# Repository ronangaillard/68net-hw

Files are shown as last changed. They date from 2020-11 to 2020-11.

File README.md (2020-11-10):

# 68net



A SCSI to ethernet board

[My blog post](https://ronangaillard.github.io/posts/68net-a-modern-scsi2ethernet-board-part1/) for more background info 

## Contributing

To make sure Kicad and git work fluently run the following before commiting :

```bash
git config --global filter.kicad_project.clean "sed -E 's/^update=.*$/update=Date/'"
git config --global filter.kicad_project.smudge cat
git config --global filter.kicad_sch.clean "sed -E 's/#(PWR|FLG)[0-9]+/#\1?/'"
git config --global filter.kicad_sch.smudge cat
```

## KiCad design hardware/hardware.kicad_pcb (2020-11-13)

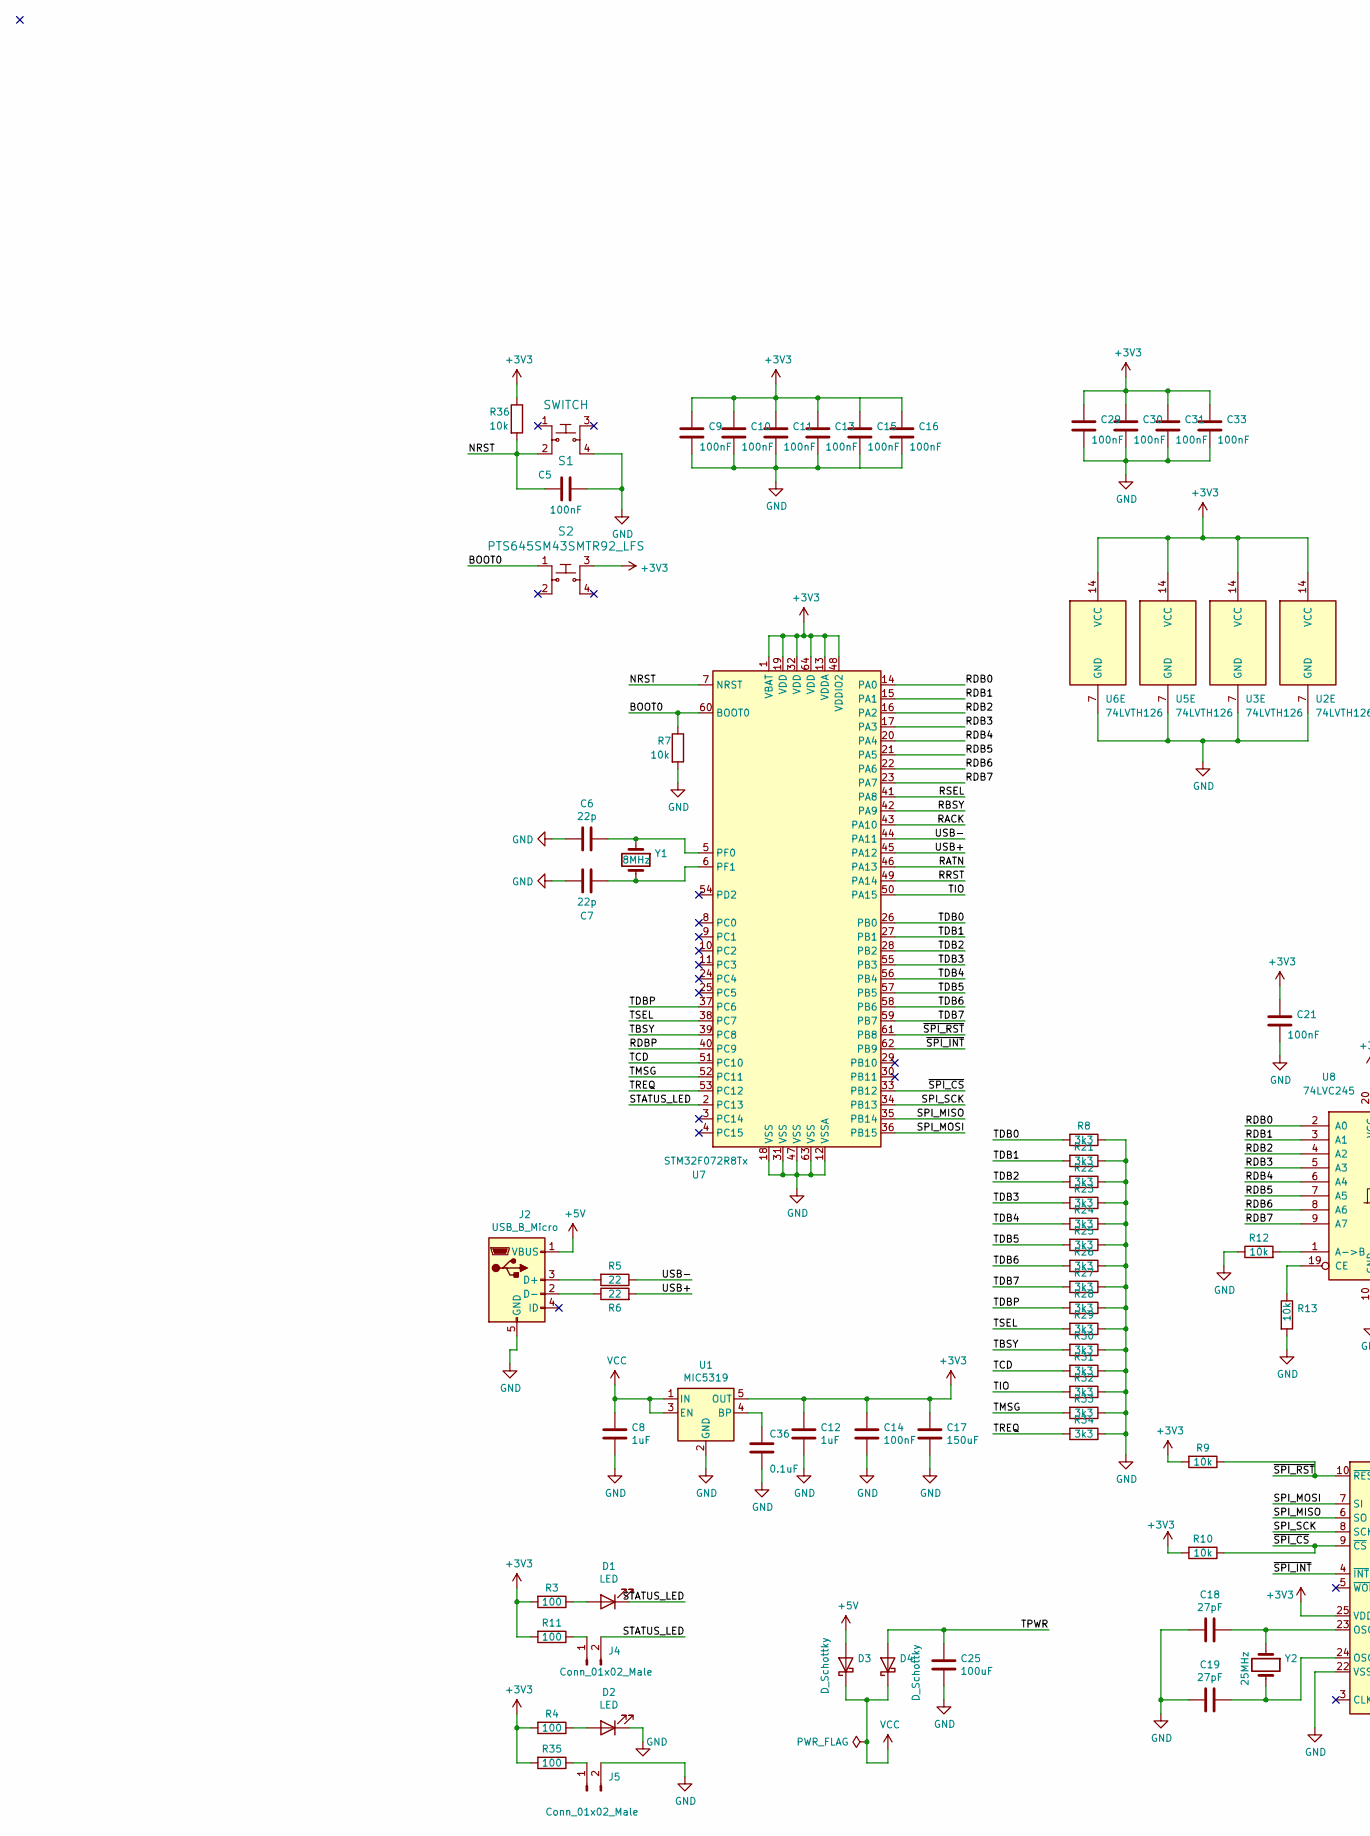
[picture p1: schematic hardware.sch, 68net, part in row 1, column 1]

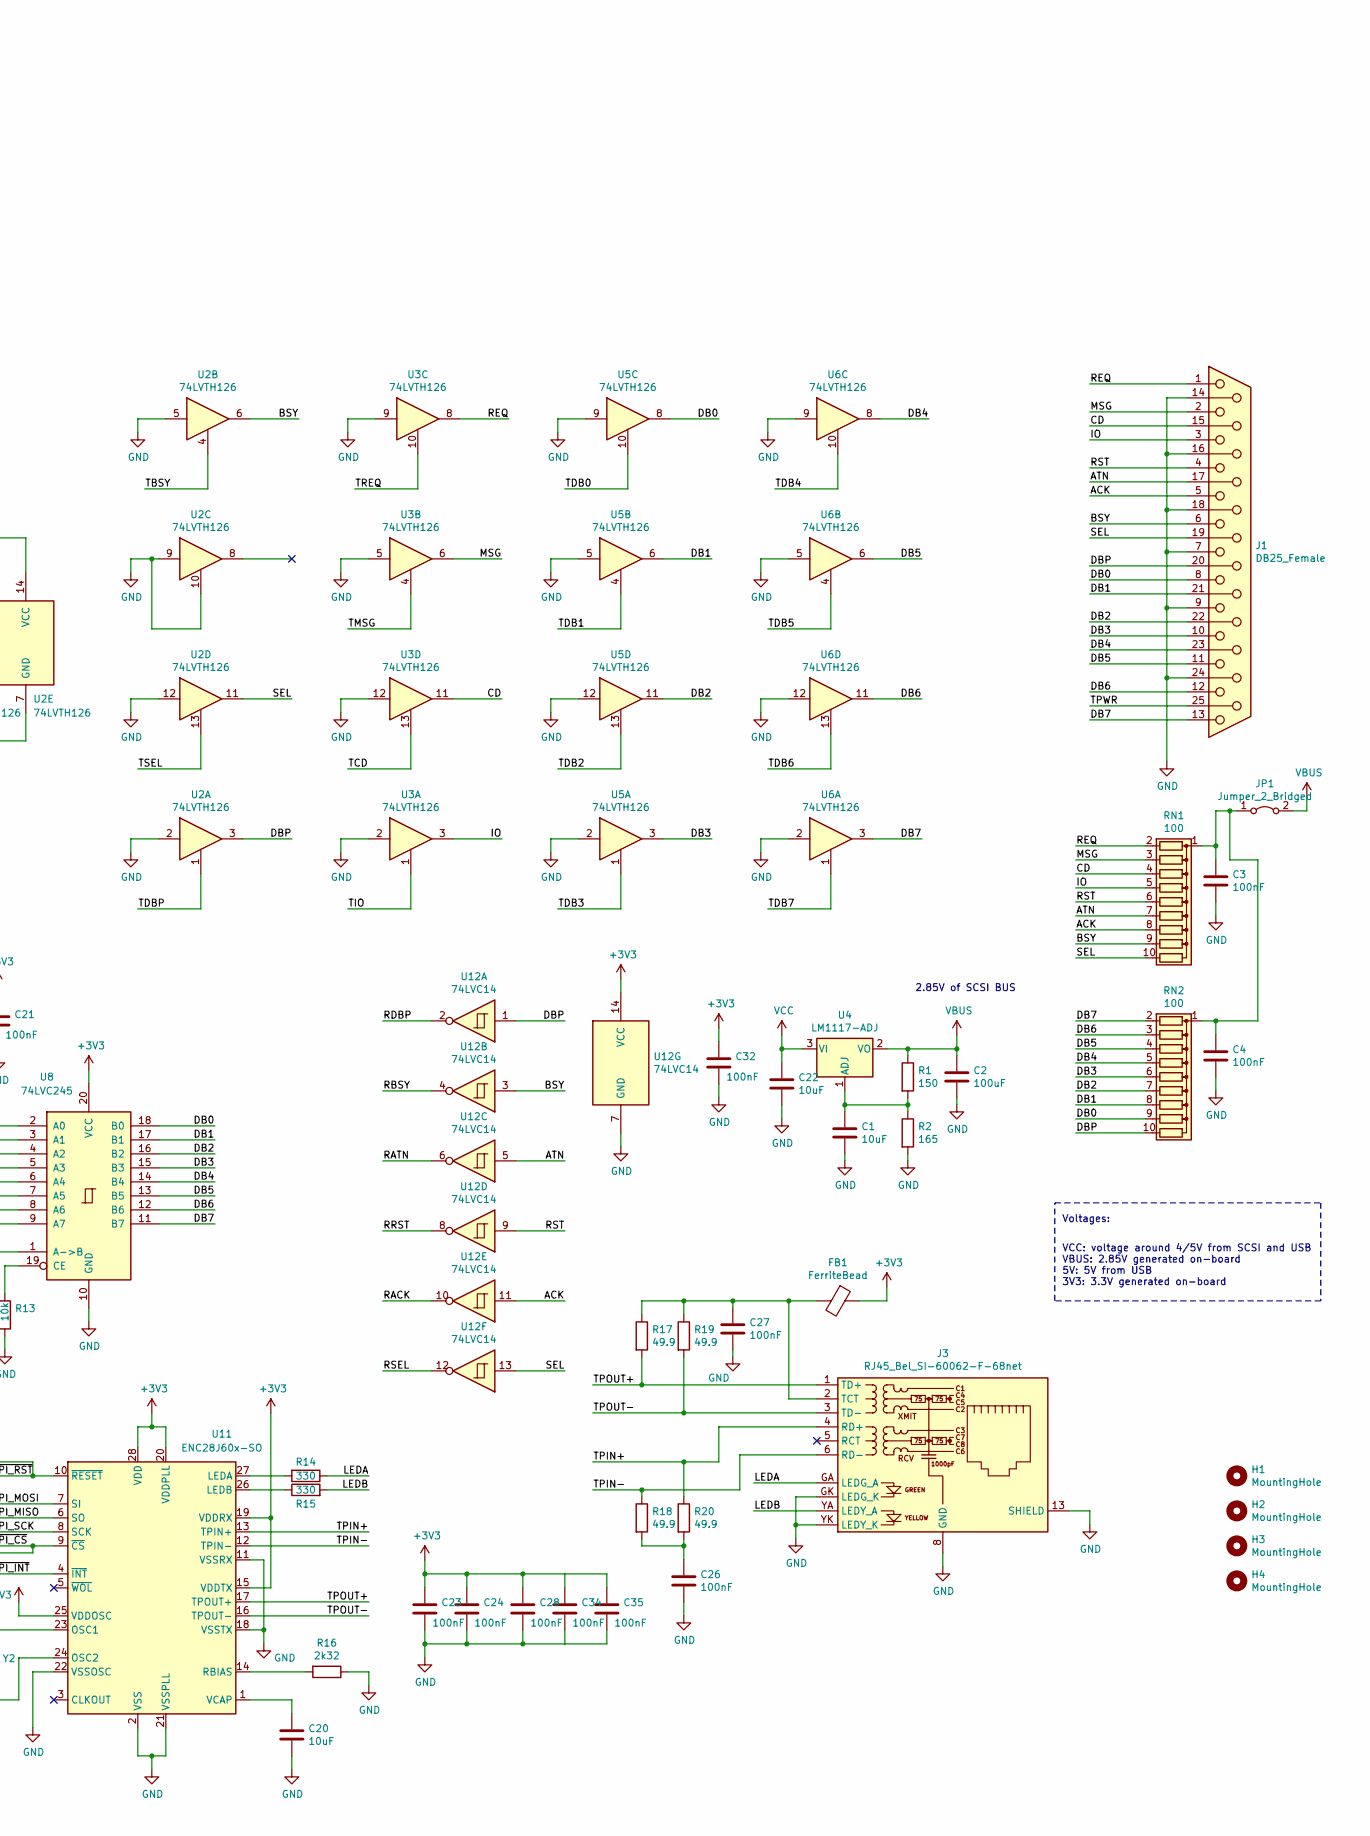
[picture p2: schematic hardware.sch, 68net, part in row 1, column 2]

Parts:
C1, C20, C22: 10uF; C_1206_3216Metric_Pad1.42x1.75mm_HandSolder; Digi-Key_PN 1276-1079-1-ND
C2: 100uF; C_1206_3216Metric_Pad1.42x1.75mm_HandSolder; Digi-Key_PN 1276-1782-1-ND
C3, C4, C5, C9, C10, C11, C13, C14, C15, C16, C21, C23, C24, C26, C27, C28, C29, C30, C31, C32, C33, C34, C35: 100nF; C_1206_3216Metric_Pad1.42x1.75mm_HandSolder; Digi-Key_PN 1276-1017-1-ND
C6, C7: 22p; C_1206_3216Metric_Pad1.42x1.75mm_HandSolder; Digi-Key_PN 1276-1203-1-ND
C8, C12: 1uF; C_1206_3216Metric_Pad1.42x1.75mm_HandSolder; Digi-Key_PN 1276-3091-1-ND
C17: 150uF; C_1206_3216Metric_Pad1.42x1.75mm_HandSolder; Digi-Key_PN 490-13964-1-ND
C18, C19: 27pF; C_1206_3216Metric_Pad1.42x1.75mm_HandSolder; Digi-Key_PN 1276-2827-1-ND
C25: 100uF; CP_Elec_6.3x5.4; Digi-Key_PN 493-2105-1-ND
C36: 0.1uF; C_1206_3216Metric_Pad1.42x1.75mm_HandSolder; Digi-Key_PN CL31B104KBCNNNC
D1, D2: LED; LED_1206_3216Metric_Pad1.42x1.75mm_HandSolder; Digi-Key_PN 60-1456-1-ND
D3, D4: D_Schottky; D_SOD-523; Digi-Key_PN RB521S30T1GOSCT-ND
FB1: FerriteBead; L_0603_1608Metric_Pad1.05x0.95mm_HandSolder; Digi-Key_PN 445-8694-1-ND
H1, H2, H3, H4: MountingHole; MountingHole_3.2mm_M3_Pad
J1: DB25_Female; DSUB-25_Female_Horizontal_Double; Digi-Key_PN 609-1507-ND
J2: USB_B_Micro; TE_2172034-1; Digi-Key_PN 135698-ND
J3: RJ45_Bel_SI-60062-F-68net; SI-60062-F; Digi-Key_PN 380-1106-ND
J4, J5: Conn_01x02_Male; PinHeader_1x02_P2.54mm_Vertical
JP1: Jumper_2_Bridged; PinHeader_1x02_P2.54mm_Vertical
R1: 150; R_0805_2012Metric_Pad1.15x1.40mm_HandSolder; Digi-Key_PN RMCF0805FT150RCT-ND
R2: 165; R_0805_2012Metric_Pad1.15x1.40mm_HandSolder; Digi-Key_PN RMCF0805FT165RCT-ND
R3, R4, R11, R35: 100; R_0805_2012Metric_Pad1.15x1.40mm_HandSolder; Digi-Key_PN RMCF0805FT165RCT-ND
R5, R6: 22; R_0805_2012Metric_Pad1.15x1.40mm_HandSolder; Digi-Key_PN RMCF0603FT22R0CT-ND
R7, R9, R10, R36: 10k; R_0805_2012Metric_Pad1.15x1.40mm_HandSolder; Digi-Key_PN RMCF0603JT10K0CT-ND
R8, R21, R22, R23, R24, R25, R26, R27, R28, R29, R30, R31, R32, R33, R34: 3k3; R_0805_2012Metric_Pad1.15x1.40mm_HandSolder
R12, R13: 10k; R_0805_2012Metric_Pad1.15x1.40mm_HandSolder
R14, R15: 330; R_0805_2012Metric_Pad1.15x1.40mm_HandSolder; Digi-Key_PN RMCF0805JT330RCT-ND
R16: 2k32; R_0805_2012Metric_Pad1.15x1.40mm_HandSolder; Digi-Key_PN RNCF0603DTE2K32CT-ND
R17, R18, R19, R20: 49.9; R_0805_2012Metric_Pad1.15x1.40mm_HandSolder; Digi-Key_PN RNCP0603FTD49R9CT
RN1, RN2: 100; R_Array_SIP10; Digi-Key_PN 4610X-1-101LF-ND
S1: SWITCH; Switch_Tactile_SMD_6x6mm; Digi-Key_PN TL3301AF160QG
S2: PTS645SM43SMTR92_LFS; Switch_Tactile_SMD_6x6mm; Digi-Key_PN TL3301AF160QG
U1: MIC5319; SOT-23-5_HandSoldering; Digi-Key_PN MIC5319-3.3YD5-TR
U2, U3, U5, U6: 74LVTH126; SOIC-14_3.9x8.7mm_P1.27mm; Digi-Key_PN 296-8663-1-ND
U4: LM1117-ADJ; SOT-223; Digi-Key_PN LM1117MPX-ADJ/NOPBCT-ND
U7: STM32F072R8Tx; LQFP-64_10x10mm_P0.5mm; Digi-Key_PN 497-17362-1-ND
U8: 74LVC245; SOIC-20W_7.5x12.8mm_P1.27mm; Digi-Key_PN 296-1232-1-ND
U11: ENC28J60x-SO; SOIC-28W_7.5x17.9mm_P1.27mm; Digi-Key_PN ENC28J60-I/SO-ND
U12: 74LVC14; SOIC-14_3.9x8.7mm_P1.27mm; Digi-Key_PN 296-1699-1-ND
Y1: 8MHz; Crystal_HC49-4H_Vertical; Digi-Key_PN 887-1253-ND
Y2: 25MHz; Crystal_HC49-4H_Vertical; Digi-Key_PN 887-1233-ND

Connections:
+3V3: C9.1, C10.1, C11.1, C12.1, C13.1, C14.1, C15.1, C16.1, C17.1, C21.1, C23.1, C24.1, C28.1, C29.1, C30.1, C31.1, C32.1, C33.1, C34.1, C35.1, FB1.1, R3.2, R4.2, R9.2, R10.2, R11.2, R35.2, R36.1, S2.3, U1.5 (OUT), U2.14 (VCC), U3.14 (VCC), U5.14 (VCC), U6.14 (VCC), U7.1 (VBAT), U7.13 (VDDA), U7.19 (VDD), U7.32 (VDD), U7.48 (VDDIO2), U7.64 (VDD), U8.20 (VCC), U11.15 (VDDTX), U11.19 (VDDRX), U11.20 (VDDPLL), U11.25 (VDDOSC), U11.28 (VDD), U12.14 (VCC)
+5V: D3.2 (A), J2.1 (VBUS)
/ACK: J1.5, RN1.8 (R7), U12.11
/ATN: J1.17, RN1.7 (R6), U12.5
/BOOT0: R7.1, S2.1, U7.60 (BOOT0)
/BSY: J1.6, RN1.9 (R8), U2.6, U12.3
/CD: J1.15, RN1.4 (R3), U3.11
/DB0: J1.8, RN2.9 (R8), U5.8, U8.18 (B0)
/DB1: J1.21, RN2.8 (R7), U5.6, U8.17 (B1)
/DB2: J1.22, RN2.7 (R6), U5.11, U8.16 (B2)
/DB3: J1.10, RN2.6 (R5), U5.3, U8.15 (B3)
/DB4: J1.23, RN2.5 (R4), U6.8, U8.14 (B4)
/DB5: J1.11, RN2.4 (R3), U6.6, U8.13 (B5)
/DB6: J1.12, RN2.3 (R2), U6.11, U8.12 (B6)
/DB7: J1.13, RN2.2 (R1), U6.3, U8.11 (B7)
/DBP: J1.20, RN2.10 (R9), U2.3, U12.1
/IO: J1.3, RN1.5 (R4), U3.3
/LEDA: J3.GA (LEDG_A), R14.1
/LEDB: J3.YA (LEDY_A), R15.2
/MSG: J1.2, RN1.3 (R2), U3.6
/NRST: C5.2, R36.2, S1.2, U7.7 (NRST)
/RACK: U7.43 (PA10), U12.10
/RATN: U7.46 (PA13), U12.6
/RBSY: U7.42 (PA9), U12.4
/RDB0: U7.14 (PA0), U8.2 (A0)
/RDB1: U7.15 (PA1), U8.3 (A1)
/RDB2: U7.16 (PA2), U8.4 (A2)
/RDB3: U7.17 (PA3), U8.5 (A3)
/RDB4: U7.20 (PA4), U8.6 (A4)
/RDB5: U7.21 (PA5), U8.7 (A5)
/RDB6: U7.22 (PA6), U8.8 (A6)
/RDB7: U7.23 (PA7), U8.9 (A7)
/RDBP: U7.40 (PC9), U12.2
/REQ: J1.1, RN1.2 (R1), U3.8
/RRST: U7.49 (PA14), U12.8
/RSEL: U7.41 (PA8), U12.12
/RST: J1.4, RN1.6 (R5), U12.9
/SEL: J1.19, RN1.10 (R9), U2.11, U12.13
/SPI_MISO: U7.35 (PB14), U11.6 (SO)
/SPI_MOSI: U7.36 (PB15), U11.7 (SI)
/SPI_SCK: U7.34 (PB13), U11.8 (SCK)
/STATUS_LED: D1.1 (K), J4.2, U7.2 (PC13)
/TBSY: R30.2, U2.4, U7.39 (PC8)
/TCD: R31.2, U3.13, U7.51 (PC10)
/TDB0: R8.2, U5.10, U7.26 (PB0)
/TDB1: R21.2, U5.4, U7.27 (PB1)
/TDB2: R22.2, U5.13, U7.28 (PB2)
/TDB3: R23.2, U5.1, U7.55 (PB3)
/TDB4: R24.2, U6.10, U7.56 (PB4)
/TDB5: R25.2, U6.4, U7.57 (PB5)
/TDB6: R26.2, U6.13, U7.58 (PB6)
/TDB7: R27.2, U6.1, U7.59 (PB7)
/TDBP: R28.2, U2.1, U7.37 (PC6)
/TIO: R32.2, U3.1, U7.50 (PA15)
/TMSG: R33.2, U3.4, U7.52 (PC11)
/TPIN+: J3.4 (RD+), R20.1, U11.13 (TPIN+)
/TPIN-: J3.6 (RD-), R18.1, U11.12 (TPIN-)
/TPOUT+: J3.1 (TD+), R17.2, U11.17 (TPOUT+)
/TPOUT-: J3.3 (TD-), R19.2, U11.16 (TPOUT-)
/TPWR: C25.1, D4.2 (A), J1.25
/TREQ: R34.2, U3.10, U7.53 (PC12)
/TSEL: R29.2, U2.13, U7.38 (PC7)
/USB+: R6.2, U7.45 (PA12)
/USB-: R5.1, U7.44 (PA11)
/~SPI_CS~: R10.1, U7.33 (PB12), U11.9 (~CS)
/~SPI_INT~: U7.62 (PB9), U11.4 (~INT)
/~SPI_RST~: R9.1, U7.61 (PB8), U11.10 (~RESET)
GND: C1.2, C2.2, C3.2, C4.2, C5.1, C6.2, C7.2, C8.2, C9.2, C10.2, C11.2, C12.2, C13.2, C14.2, C15.2, C16.2, C17.2, C18.2, C19.2, C20.2, C21.2, C22.2, C23.2, C24.2, C25.2, C26.2, C27.2, C28.2, C29.2, C30.2, C31.2, C32.2, C33.2, C34.2, C35.2, C36.2, D2.1 (K), J1.7, J1.9, J1.14, J1.16, J1.18, J1.24, J2.5 (GND), J3.8 (GND), J3.13 (SHIELD), J3.GK (LEDG_K), J3.YK (LEDY_K), J5.2, R2.2, R7.2, R8.1, R12.1, R13.2, R16.1, R21.1, R22.1, R23.1, R24.1, R25.1, R26.1, R27.1, R28.1, R29.1, R30.1, R31.1, R32.1, R33.1, R34.1, S1.4, U1.2 (GND), U2.2, U2.5, U2.7 (GND), U2.9, U2.10, U2.12, U3.2, U3.5, U3.7 (GND), U3.9, U3.12, U5.2, U5.5, U5.7 (GND), U5.9, U5.12, U6.2, U6.5, U6.7 (GND), U6.9, U6.12, U7.12 (VSSA), U7.18 (VSS), U7.31 (VSS), U7.47 (VSS), U7.63 (VSS), U8.10 (GND), U11.2 (VSS), U11.11 (VSSRX), U11.18 (VSSTX), U11.21 (VSSPLL), U11.22 (VSSOSC), U12.7 (GND)
unnamed: C1.1, R1.2, R2.1, U4.1 (ADJ)
unnamed: C3.1, C4.1, JP1.1 (A), RN1.1 (common), RN2.1 (common)
unnamed: C6.1, U7.5 (PF0), Y1.1
unnamed: C7.1, U7.6 (PF1), Y1.2
unnamed: C18.1, U11.23 (OSC1), Y2.1
unnamed: C19.1, U11.24 (OSC2), Y2.2
unnamed: C20.1, U11.1 (VCAP)
unnamed: C26.1, R18.2, R20.2
unnamed: C27.1, FB1.2, J3.2 (TCT), R17.1, R19.1
unnamed: C36.1, U1.4 (BP)
unnamed: D1.2 (A), R3.1
unnamed: D2.2 (A), R4.1
unnamed: J2.2 (D-), R6.1
unnamed: J2.3 (D+), R5.2
unnamed: J4.1, R11.1
unnamed: J5.1, R35.1
unnamed: R12.2, U8.1 (A->B)
unnamed: R13.1, U8.19 (CE)
unnamed: R14.2, U11.27 (LEDA)
unnamed: R15.1, U11.26 (LEDB)
unnamed: R16.2, U11.14 (RBIAS)
VBUS: C2.1, JP1.2 (B), R1.1, U4.2 (VO)
VCC: C8.1, C22.1, D3.1 (K), D4.1 (K), U1.1 (IN), U1.3 (EN), U4.3 (VI)

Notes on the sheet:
2.85V of SCSI BUS
VCC: voltage around 4/5V from SCSI and USB VBUS: 2.85V generated on-board 5V: 5V from USB 3V3: 3.3V generated on-board
Voltages:

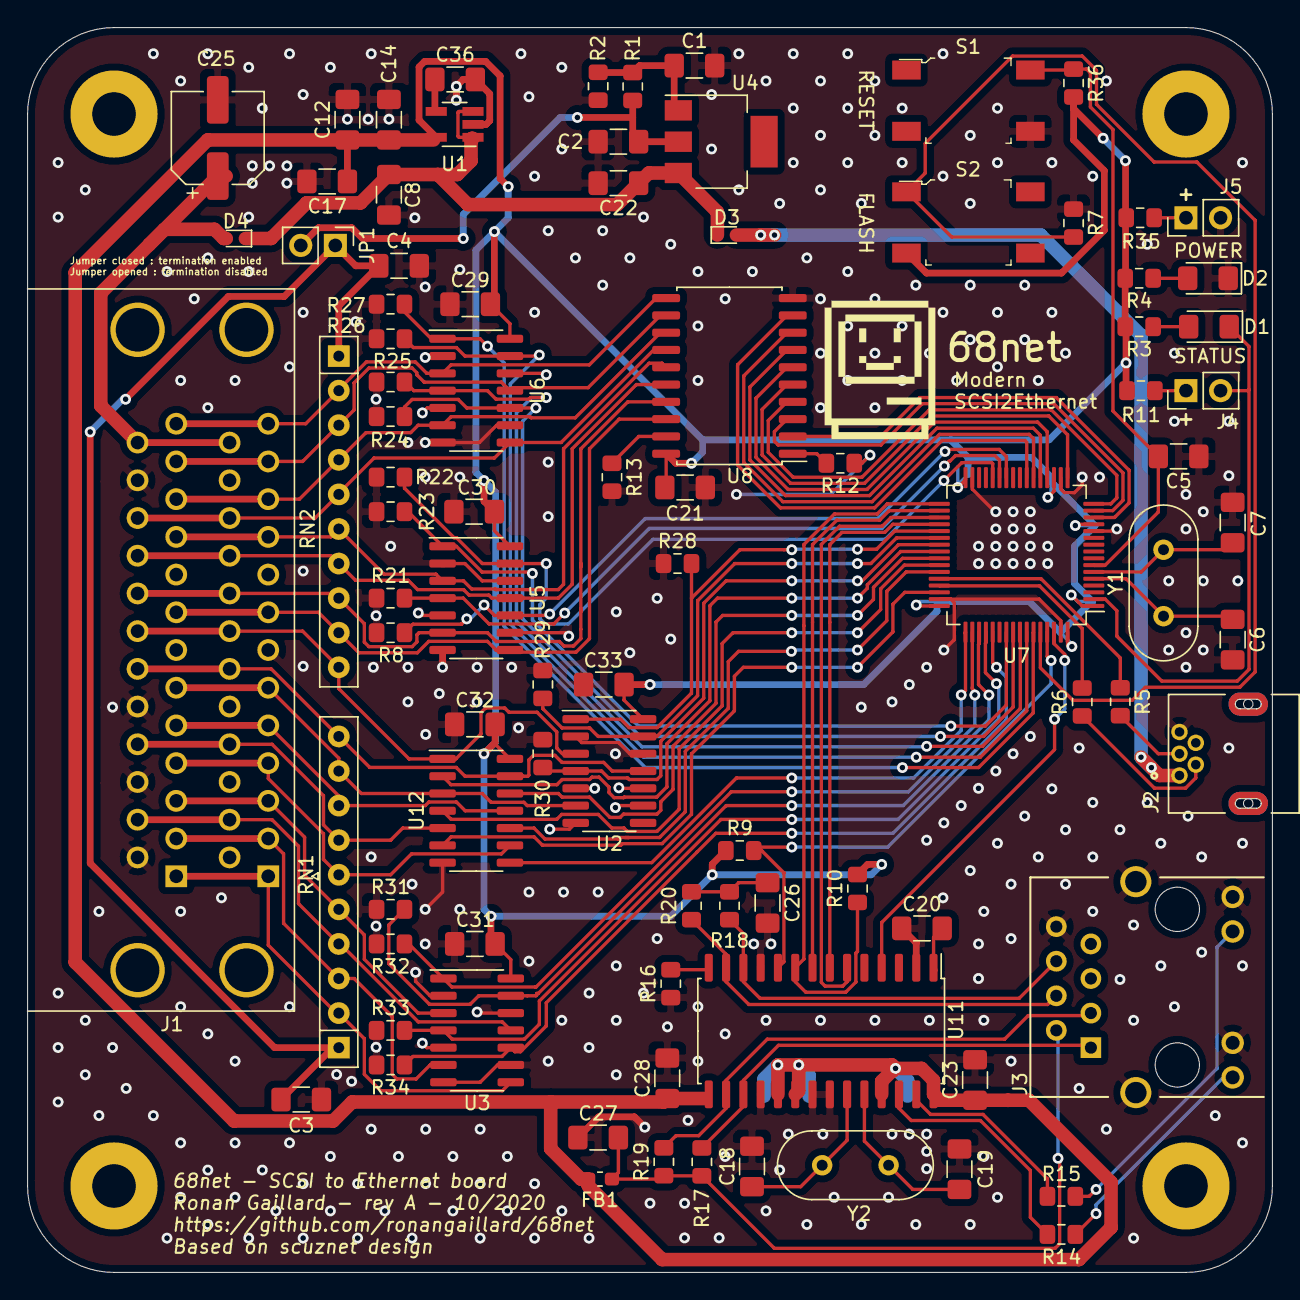
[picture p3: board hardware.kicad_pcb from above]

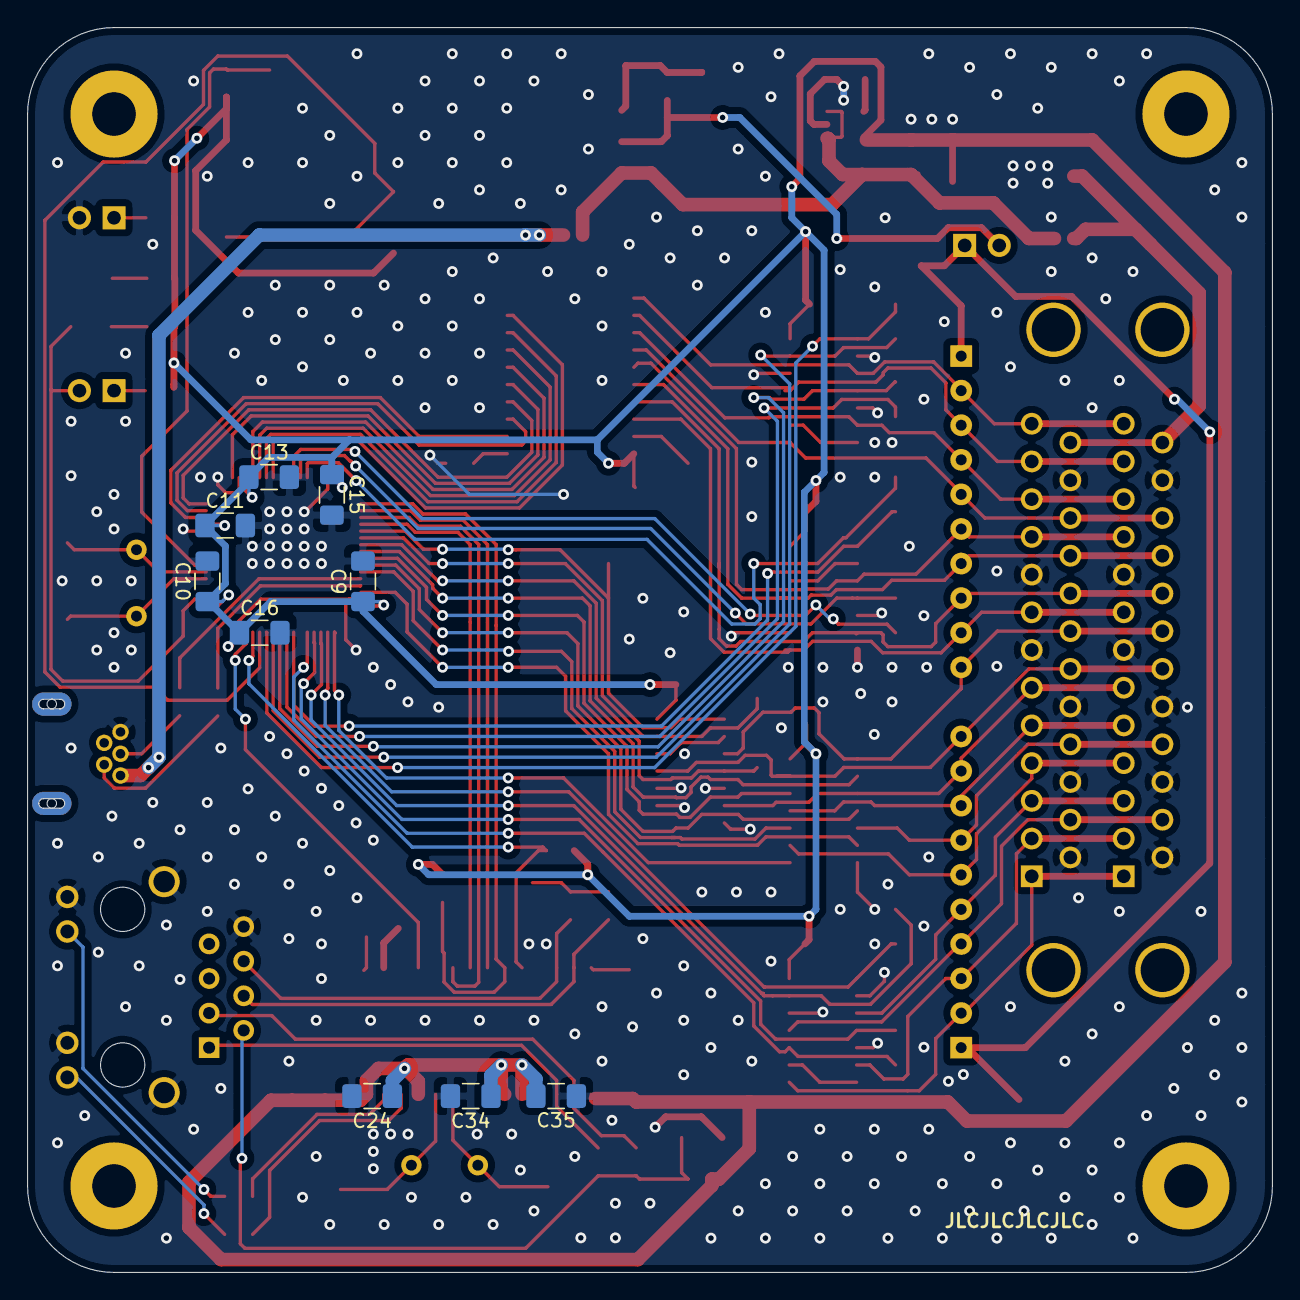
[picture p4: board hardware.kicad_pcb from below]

Board: 2 copper layers, 91.4 x 91.4 mm, 103 parts (9 on the bottom side), 91 nets.

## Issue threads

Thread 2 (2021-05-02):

Termination enable/disable incorrect

MattiNummi, 2021-05-02:
You cannot disable/enable termination with connecting/disconnecting termination power.
You must disconnect the termination resistors so that there is no connection between signals.
Just imagine, that You drive 15 signals to 0 volts. This creates a grounding resistance about 110/15 = 7 Ohms.
At the same time the other end "computer" drives one signal 2.85V through 110 Ohms to the line.
This makes the signal drop to:    2.85V * (110+7) / (110+110+7)  =  1.47V.

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

ronangaillard, 2021-11-26:
Sorry, not sure why but I just saw your message/issue.

You're completely right, I'm going to fix this asap.

Do you have any hints to solve this ?

Thanks :)

MattiNummi, 2021-11-27:
Hi Ronan,

Old SCSI-2 termination chips are not available anymore.

You can check options form SCSI2SD.

http://www.codesrc.com/mediawiki/index.php/SCSI2SD

Order is not any preference:

1. Use LVT125 to drive termination power to termination resistors
2. Use CU861 - SN74CBT3861 10-BIT FET BUS SWITCH to connect the termination resistors to termination power
3. Use resistor packs in a socket to enable the termination (SCSI2SD v 5.01a if I remember correctly).
4. No termination, good option for the first version. Termination can always be provided externally. And added to next versions.

Have done any SCSI firmware programming? I would be interested.
Best Regards,
Matti Nummi
________________________________________
Lähettäjä: Ronan Gaillard ***@***.***>
Lähetetty: perjantai 26. marraskuuta 2021 21.47
Vastaanottaja: ronangaillard/68net-hw
Kopio: Matti Nummi; Author
Aihe: Re: [ronangaillard/68net-hw] Termination enable/disable incorrect (#2)

Sorry, not sure why but I just saw your message/issue.

You're completely right, I'm going to fix this asap.

Do you have any hints to solve this ?

Thanks :)

—
You are receiving this because you authored the thread.
Reply to this email directly, view it on GitHub<https://github.com/ronangaillard/68net-hw/issues/2#issuecomment-980364186>, or unsubscribe<https://github.com/notifications/unsubscribe-auth/AQ7CJNB2NTO5OBJLEEF7SM3UN7P5XANCNFSM437QDCPA>.
Triage notifications on the go with GitHub Mobile for iOS<https://apps.apple.com/app/apple-store/id1477376905?ct=notification-email&mt=8&pt=524675> or Android<https://play.google.com/store/apps/details?id=com.github.android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>.

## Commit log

2020-11-04 fix: drc and unused pins
    [hardware.sch]
2020-11-04 feat: update page settings
    [hardware.sch]
2020-11-04 feat: update extension port and place again footprints on pcb
    [hardware.kicad_pcb]
2020-11-04 feat: split 15 resistor array into single resistors
    [hardware.sch]
2020-11-10 feat: finalize revA-alpha
    [hardware.kicad_pcb, hardware.sch]
2020-11-10 feat: add jumper connector to enable termination
    [hardware.kicad_pcb, hardware.sch]
2020-11-10 feat: update LDO regulator
    [hardware.kicad_pcb, hardware.sch]
2020-11-11 feat: add double DB25 connector
    [hardware.kicad_pcb]
2020-11-12 feat: add connectors for external LEDs
    [hardware.kicad_pcb, hardware.sch]
2020-11-12 fix: boot and rst signal badly pulled up/down
    [hardware.kicad_pcb, hardware.sch]
2020-11-13 fix: wrong pins on LEDs connectors
    [hardware.kicad_pcb, hardware.sch]
2020-11-13 feat: add JLCJLC... +fix trace touching usb shield
    [hardware.kicad_pcb]
2020-11-17 feat: update BOM
    [hardware.sch]
